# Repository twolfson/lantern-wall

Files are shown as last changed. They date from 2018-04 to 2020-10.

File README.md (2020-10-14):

# lantern-wall
Documentation for a glowing lantern wall

## Summary
While decorating my apartment, I decided to leverage a picture rail and attempted to make a wall of [Cloud Clouds][]

[Cloud Clouds]: https://learn.sparkfun.com/tutorials/led-cloud-connected-cloud

During the process, I realized that clouds would look too bulky for what I wanted as well as require a lot more thought to power/illumination

Now the result is one-off perf-boards with a CR2032 battery, LED, switch, and weak resistor

**Off:**

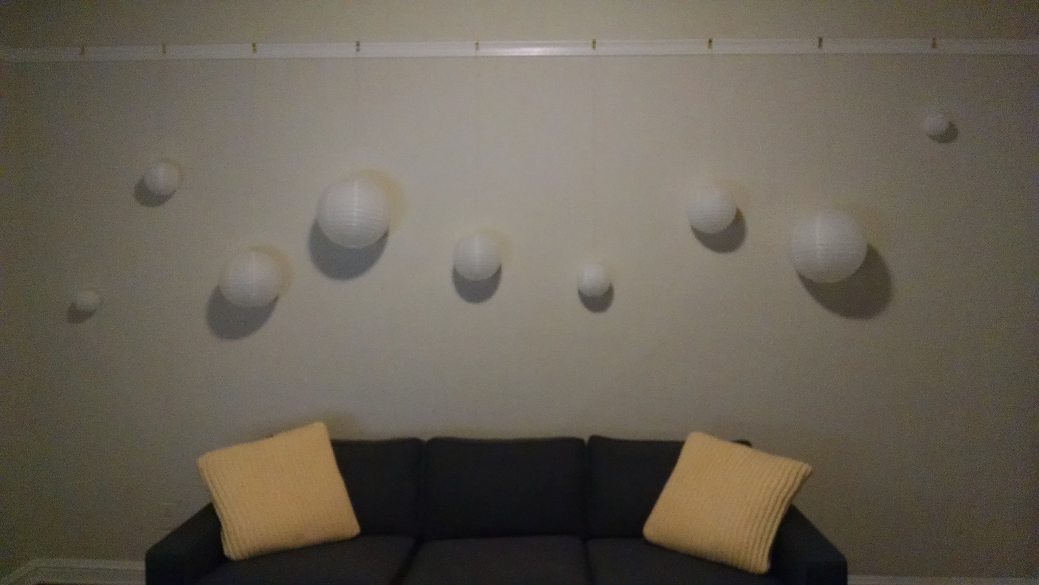
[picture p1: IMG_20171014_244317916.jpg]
Lanterns off


**On, room lights on:**

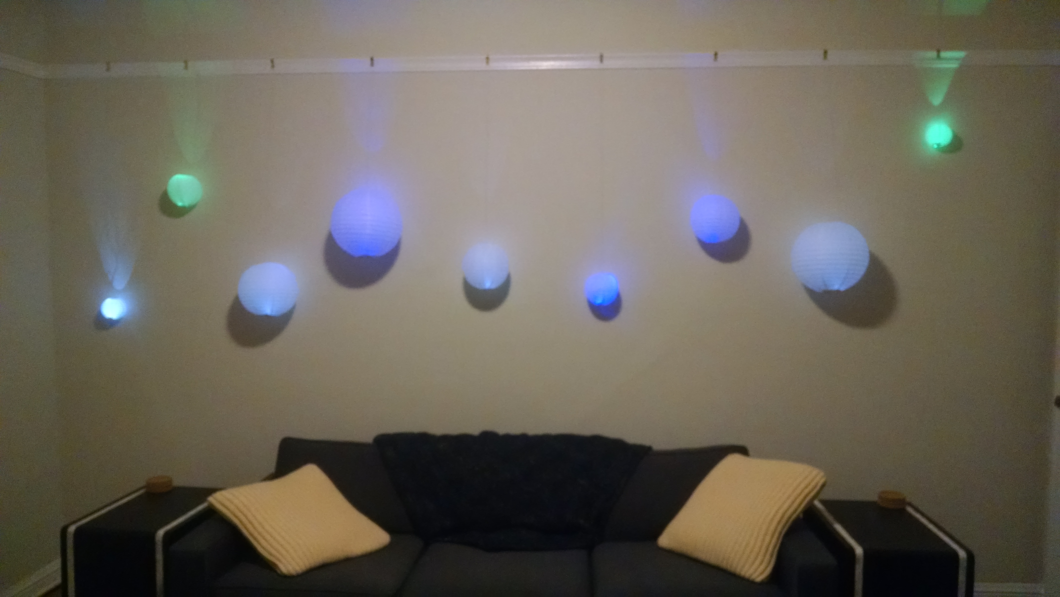
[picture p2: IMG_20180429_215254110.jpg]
Lanterns on, room lights on


**On, room lights off:**

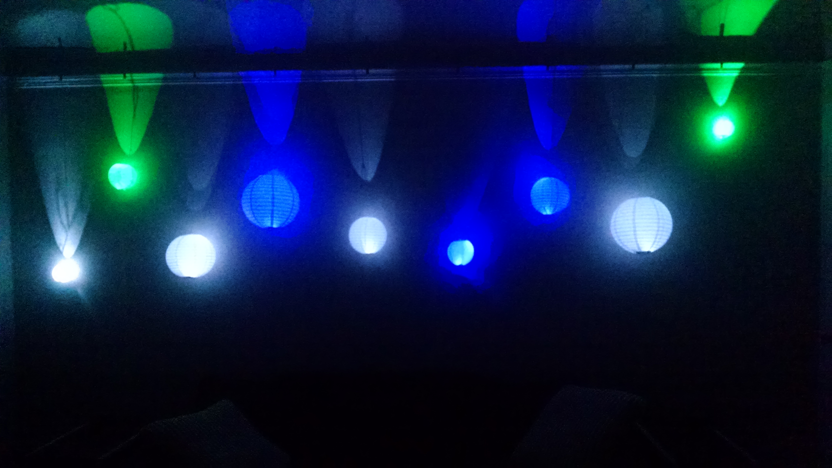
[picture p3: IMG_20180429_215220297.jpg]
Lanterns on, room lights off


**All photos:**

<https://drive.google.com/drive/folders/1h23Px1IOjGWnXOu8yB6WGrw3N42IKGuf?usp=sharing>

## Hardware
Each lantern has 1 or 2 boards in it. The boards are made out of perfboard so I have some rigidity and get some solder practice (I'm new to electronics)

**Circuit photo:**

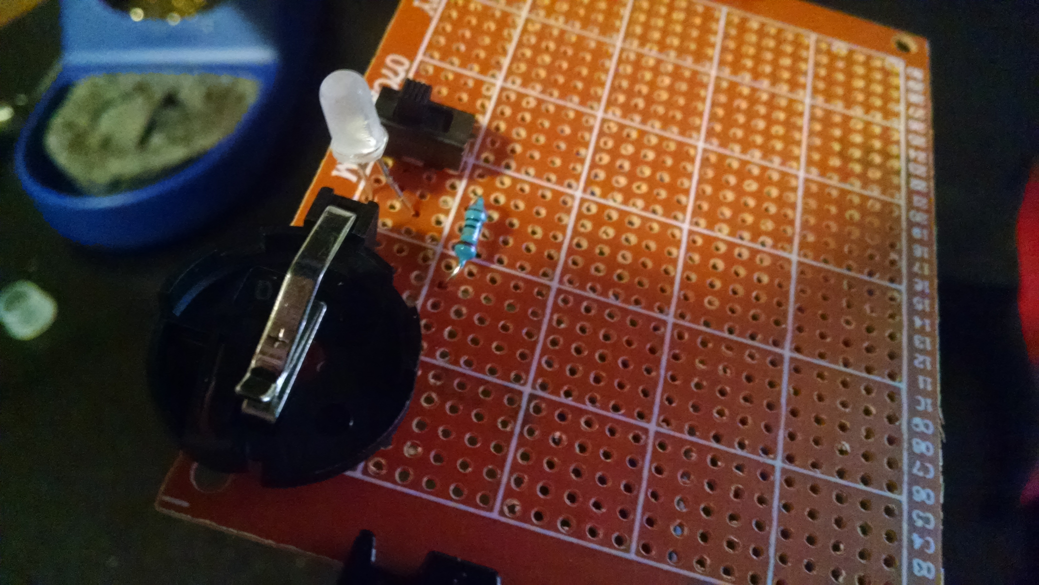
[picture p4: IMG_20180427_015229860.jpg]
Circuit photo


**Board components:**

- Perfboard, https://www.adafruit.com/product/2670
    - 1 perfboard used to create six boards
    - Effective price: $0.08/LED board
- CR2032 holder, https://www.amazon.com/gp/product/B00NQB2UNU/
    - Effective price: $0.60/LED board
- CR2032 batteries, https://www.amazon.com/gp/product/B071D4DKTZ/
    - Effective price: $0.70/LED board
- LEDs, https://www.amazon.com/gp/product/B01AUI4VSI/
    - We modified these with 400 grit sandpaper to diffuse them
    - Effective price: $0.08/LED board
- 10 ohm resistors, https://www.amazon.com/gp/product/B072BL2VX1/
    - Effective price: $0.02/LED board
- Switch, https://www.amazon.com/gp/product/B007QAJST6/
    - Effective price: $0.13/LED board

**Non-board components:**

- Lanterns, https://www.amazon.com/gp/product/B01M63OEBF/
- Picture rail hooks, bought at local hardware store
- String, bought at local sewing store

**Total prices:**

- Total price per LED board: $1.61
- LED boards made, excluding early lessons: 12
- Total price for entire project: $32.32

## Pros
- Boards are tiny and fit smallest lanterns
    - Had trouble finding something off the shelf, hence the boards

## Cons
- CR2032's aren't reusable
- Current for LEDs gets lower over time
    - Due to being new to electronics, I didn't realize batteries aren't constantly at their nominal output voltage
    - As a result CR2032 starts at 3.3V but then gets down to 2.7V
    - The result is the LED draws ~20mA then down to ~3mA leading in 10x dimmer brightness

## If I were to do it again
- Use lithium polymer batteries
    - Would maximize current and allow recharging

## Documentation
### Photos
We've uploaded all the photos from this project to Google Drive. The dates will correlate with the notes here

<https://drive.google.com/drive/folders/1h23Px1IOjGWnXOu8yB6WGrw3N42IKGuf?usp=sharing>

### October 14 2017
Hung up initial lanterns on picture rail utilizing string + tape to find ideal height

We also tried out using cotton on a cloud but didn't like the result so we left it as is for now

**Notes:**

- [2017-10-14-initial-hanging-readme.md](2017-10-14-initial-hanging-readme.md)
- [2017-10-14-dye-considerations.png](2017-10-14-dye-considerations.png)

### December 03 2017
Walking through Chinatown I saw this lantern display and took a photo

I don't think I ever registered it as the inspiration for this project but it probably was subconciously

### March 30 2018
Performed lighting tests for a single LED in a lantern, utilizing a breadboard

Figuring out logistics for putting a battery and board inside of the smallest lantern

**Notes:**

- [2018-03-and-04-planning.txt](2018-03-and-04-planning.txt)

### April 04 2018
All necessary parts arrived, soldered up our first board

My soldering inexperience is showing here with lots of doubly-thick solder runs

However it worked and I was thrilled

**Notes:**

- [2018-04-04-first-light.txt](2018-04-04-first-light.txt)

## April 10 and 11 2018
Taking time to explore new solder and research getting a respirator

It definitely made me more confident in future soldering and have a better understanding of what is going on

**Notes:**

- [2018-04-10-soldering-notes.txt](2018-04-10-soldering-notes.txt)
- [2018-04-11-deciding-on-respirator.txt](2018-04-11-deciding-on-respirator.txt)

## April 15 2018
Lots of things happening that day:

- Tried out new respirator with quick latch
    - Quick latch is soooo useful
- Soldered another board
- Noticed lighting in lantern was weird
- Contemplated different hanging/insertion approaches to fix directionality
- Proof of concept showed that it didn't matter where light was, it was a lack of diffusion causing issue
- Diffused the LED via 400 grit sandpaper, worked great in proof of concept
- Made a board with diffused LED, worked great
- Explored color ideas on computer
- Started to build proof of concept color circuits but it got too late

**Notes:**

- [2018-04-15-respirator-fitting.txt](2018-04-15-respirator-fitting.txt)
- [2018-04-15-making-boards.txt](2018-04-15-making-boards.txt)
- [2018-04-15-lighting-explore.png](2018-04-15-lighting-explore.png)
- [2018-04-15-lighting-explore-cool-colors.png](2018-04-15-lighting-explore-cool-colors.png)
- [2018-04-15-lighting-explore-cool-colors-without-uv.png](2018-04-15-lighting-explore-cool-colors-without-uv.png)
    - Went with non-UV variant to avoid freaking people out due to length UV exposure (despite likely being harmless UVA)

## April 22 2018
- Tried out a new solder to avoid splatter, still getting some splatter
    - Advice/feedback here would be much appreciated. Iron is at 750F, solder is lead-free rosin core 2%
- Tried out finding minimal resistance for LED via potentiometer :sparkles:
- Tried out color proof of concept with throwie-esque LEDs

**Notes:**

- [2018-04-22-color-proof-of-concept.txt](2018-04-22-color-proof-of-concept.txt)
- [2018-04-22-new-solder.txt](2018-04-22-new-solder.txt)
- [2018-04-22-resistance-testing.txt](2018-04-22-resistance-testing.txt)

## April 23 2018
Realized that CR2032 would need to be replaced at some point and isn't recharagable. Started a battery test to see how voltage, current, and battery life hold up over time. It's been still going as of 2018-04-29 ._.

**Notes:**

- [2018-04-23-battery-test.txt](2018-04-23-battery-test.txt)

## April 24, 26, 28, and 29 2018
Soldered remaining boards and hung them up to get our final product. Also did some calculations to see how much longer the battery test would go on for

- [2018-04-24-more-soldering.txt](2018-04-24-more-soldering.txt)
- [2018-04-26-even-more-soldering.txt](2018-04-26-even-more-soldering.txt)
- [2018-04-28-battery-test-visualization.xls](2018-04-28-battery-test-visualization.xls)
- [2018-04-29-final-hanging.txt](2018-04-29-final-hanging.txt)

Final product:

**Off:**

Lanterns off

**On, room lights on:**

Lanterns on, room lights on

**On, room lights off:**

Lanterns on, room lights off

## October 2018
We revisited the project to make it easier to turn lights on/off. The old process was:

- Wiggle circuit out of lantern
- Toggle switch
- Wiggle circuit back into lantern

Wiggling can take an annoying amount of time

We did some research and settled on the following triggering our lanterns:

- Magnetic reed switches, https://www.amazon.com/gp/product/B07239WZGF/
    - Effective price: $0.45/board
    - Buying excess of these is necessary as they are fragile and easily break when affixing to existing circuits
- Bar magnets, https://www.amazon.com/gp/product/B00BZ9YU88/
    - Effective price: $1.06/lantern

We can now slide in/out the bar magnet on the bottom of the lantern which is marginally easier and still consumes no power

## May 2020
After enough time, we found inserting/removing magnets each time was tedious to do for all 9 boards

We considered many alternatives (e.g. pull cord switch, capacitive touch, solid-state relays) and for a long time thought that low-current draw would be too high

We were wrong about low-current draw being too much, as 0.1uA from an [ATtiny85][] works great for our purposes =)

We settled on the [ATtiny85][] as opposed to other ICs for the following reasons:

- Through-hole solid-state relays draw more current in quiescent state (at least 1uA, vs 0.1uA for ATtiny @ 3.3V)
    - Example: https://www.digikey.com/product-detail/en/toshiba-semiconductor-and-storage/TLP222AF/TLP222AF-ND/871243
- Battery is only 200mAh so 2 years of idling drains 1% (~2mAh; `0.1uA * 1mA/1000uA * 2y * 365d/1y * 24h/365d`) vs 10% for `1uA`
- Easy wiring with built-in pull-up resistor for interrupt
- Discovered `PIC12F629` too late, which allows for `1nA` current on sleep, but already had ATtiny/AVR programmer
    - https://www.jameco.com/Jameco/Products/ProdDS/223790.pdf

We were also excited about features like:

- Keeping LED on while ATtiny is asleep (only works for `digitalWrite`/`HIGH`, no `analogWrite`/PWM support)
- Potential to use for twinkling (contrary to previous line)
- Potential to use for RGB LEDs, once we more thoroughly learn about power requirements and battery options

[ATtiny85]: https://www.microchip.com/wwwproducts/en/ATtiny85

We prototyped and created new boards with this setup, detailed info can be found in `2020-05-magnet-toggle.txt`

Additionally an [PlatformIO][] setup and perfboard [Fritzing][] layouts can be found in the corresponding `magnet-toggle` folder

The `.cpp` file in this folder is also compatible as an [Arduino][] sketch

> Using Fritzing after our first couple boards significantly sped up production since we didn't have to overthink placement as much

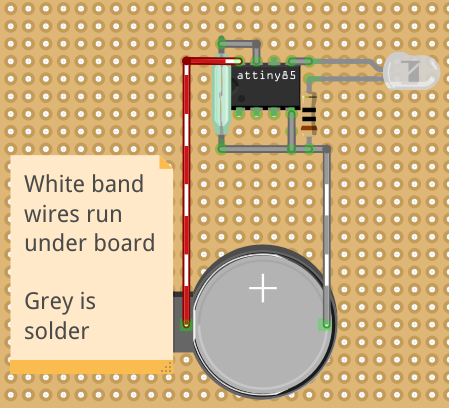
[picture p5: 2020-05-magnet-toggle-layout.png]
Fritzing layout


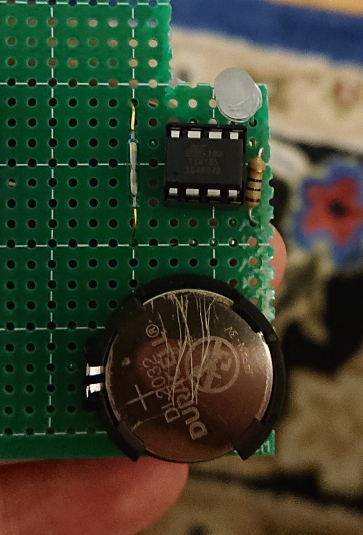
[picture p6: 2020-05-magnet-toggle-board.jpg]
Board result


[PlatformIO]: https://platformio.org/
[Arduino]: https://www.arduino.cc/
[Fritzing]: https://fritzing.org/home/

Bill of Materials (BOM) per 1 LED board:

- 7x9cm single sided perfboard, $0.75 each, https://www.mdfly.com/products/5pcs-hq-7-9cm-single-side-prototype-board-perforated-2-54mm-plated-breadboard.html
    - Can use a much smaller size in practice and pad out edges with cardboard underneath
- 8 pin DIP socket, $0.12 each, https://www.jameco.com/webapp/wcs/stores/servlet/ProductDisplay?productId=51571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
    - Kind of sticky to microcontrollers, recommend buying [DIP IC extractor](https://www.jameco.com/webapp/wcs/stores/servlet/ProductDisplay?productId=16838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) as well
- ATtiny85, $1.75 each, https://www.jameco.com/webapp/wcs/stores/servlet/ProductDisplay?productId=2151312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
- CR2032 holder, $0.55 each, https://www.jameco.com/webapp/wcs/stores/servlet/ProductDisplay?productId=355434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
    - These were much less brittle than the earlier versions we bought, very satisfied
- Reed switch - normally open, $0.50 each, https://www.mdfly.com/products/hq-2-7x14mm-reed-switch-no-pack-of-2.html
    - Highly recommend plastic over glass as glass can break easily during handling
- LEDs, $0.40 at most each
    - White, failed to get right brightness+color temperature from Jameco, went back to Chanzon, https://smile.amazon.com/gp/product/B01AUI4VSI/
    - Green, leftover from first iteration, https://smile.amazon.com/gp/product/B01AUI4VSI/
    - Blue, https://www.jameco.com/webapp/wcs/stores/servlet/ProductDisplay?productId=2274839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
- 10 ohm resistor, $0.06 each, https://www.jameco.com/webapp/wcs/stores/servlet/ProductDisplay?productId=690380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
- Not listed: Solid core wire, solder, CR2032 battery, etc

## Unlicense
As of Apr 29 2018, Todd Wolfson has released this repository and its contents to the public domain.

It has been released under the [UNLICENSE][].

[UNLICENSE]: UNLICENSE

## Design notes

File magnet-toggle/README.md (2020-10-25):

# lantern-wall/magnet-toggle
Magnet toggle source code for a lantern wall lantern

## Getting started
**Requirements:**

- ATtiny85 programmer, e.g. [Tiny AVR Programmer][]
- ATtiny85

[Tiny AVR Programmer]: https://www.sparkfun.com/products/11801

**Steps:**

Connect the ATtiny85 and ATtiny85 programmer to your computer, then run the following in a terminal:

```bash
# If PlatformIO isn't yet installed, we recommend installing it via `virtualenvwrapper`
# mkvirtualenv lantern-wall

# Configure out ATtiny85 fuses
platformio run --target fuses
# Processing attiny85 (platform: atmelavr; board: attiny85; framework: arduino)
# ...
# avrdude done.  Thank you.

# Program our board
platformio run --target upload
# Processing attiny85 (platform: atmelavr; board: attiny85; framework: arduino)
# ...
# avrdude done.  Thank you.
```

The ATtiny85 is now programmed and ready to be used in a circuit.

Please see the [Fritzing][] files (`.fzz`) for wiring layout

[Fritzing]: https://fritzing.org/home/

## Documentation
### Development
If rewriting the script, then we recommend doing all dev on the programmer itself:

- Connect jumper wires to interrupt pin (PB2) and GND, then connect them to simulate a switch closing

If doing more detailed exercises like determining power usage, then V_CC will need to be proxied somehow which cannot be done in place

As a reminder: A 3.3V powered ATtiny cannot be powered by a 5V USB jumper, not only due to being on a different V_CC and GND but also due to different logic levels

Additionally, using 5V power with an LED might cause burnout, if the resistor is too weak

In short, it's probably best to build a development board which has a resistor sturdy enough for 5V and headers for jumping everything from the programmer board (including a V_CC proxy)

## Architecture
We use PlatformIO for our project, to avoid dancing between different Arduino IDE setups

As well as document our setup itself as code (e.g. clock speed, fuses)

## Notes
- Starting point for current code: 0.2uA LED off, 1.67mA LED on
- We tried downclocking it but have bricked the ability to program it .\_. https://www.avrfreaks.net/forum/attiny85-configured-128-khz-internal-oscillator-does-not-program-anymore
  - The ATtiny85 still does work for our lanterns, but yea. Stuck at unable to program =/
  - Going to put it off to the side
- Moved to newer code and fuses, seems to use same 0.1uA when LED off but 1.90mA with LED on
- Rolled back code and fuses, power consumption is indistinguishable (only real changes were analog comparator disable and pins change)
  - Though couldn't turn on LED in 200uA multimeter mode with new code/fuses. Possibly requires CKDIV8 for slower/less power hungry boot
- We've confirmed that it was the CKDIV8 fuse, rolling back that change now
- Probably won't reprogram all the boards since not a necessary change but good exploration for ourselves =)

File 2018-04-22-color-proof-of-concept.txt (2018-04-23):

Exploring color proof of concept

Initial attempt:

- Take a CR2032
- Put it in a holder
- Wrap resistor around 1 pole and tape it
- Wrap LED around other pole and tape it
- Connect remaining ends and tape them together

Doesn't work very well. Components too loose

Second attempt:

Make a throwie minus the magnet

- Take a CR2032
- Put LED on both its ends
- Tape it
- Done

Good, just don't hold it for too long due to no resistor

Could also inline a resistor for the LED but don't really want to

-----------------------

Okay, back and deciding to still use a resistor. It was bugging out with the LED a little earlier

Going to also diffuse all LEDs for this experiment

- [5 of 5] White LEDs (3 singles, 1 double)
- [4 of 4] Blue  LEDs (2 singles, 1 double)
- [2 of 2] Green LEDs (2 singles)

After some more trial/error, layout attempt that works best is to make both LED and resistor linear/tightly packed battery then wrap their ends

This minimizes the leads slipping from the tape

```
// Off/disconnected
      & // LED
     * *
 ****   ***
+++++
-----
 ****   ****
     ~~~  // Resistor

// On/connected
      & // LED
     * *
 ****   *
+++++    ** // Twisted wires
-----    ***
 ****   *
     ~~~  // Resistor
```

It also helps to do an L bend on the battery side so they resist flipping

Ammeter checks:

- Green LED: 10mA with 10 ohm resistor
- White LED: 8mA with 10 ohm resistor
- Blue LED: 8mA with 10 ohm resistor

I'm going to bet they'll be a little more in a breadboard, no idea in circuit since we'd need to break the circuit (e.g. pluggable wires)

Since we had 20mA on breadboard previously

All done and wired up

The board LED is definitely brighter than the taped LED

Connected all of the LEDs

It turns out I miscounted and needed to use a non-diffused LED

Everything looks good

The brightnesses do vary a lot but I think that's alright

It's art, it doesn't have to be perfect/consistent

The proper fix for this would be to swap our the resistors with potentiometers and tune the resistance appropriately

Correction to my previous claim about being unable to test circuit board with an ammeter. It's possible if we turn off the switch and short-circuit around it with the ammeter

Anyway, going to move forward with 10 ohm boards for each LED

And add 1 more white LED to the list

The pattern goes from left to right

- Size 1. 1 white LED
- Size 2. 1 green LED
- Size 4. 2 white LEDs
- Size 5. 2 blue  LEDs
- Size 3. 1 white LED
- Size 2. 1 blue  LED
- Size 3. 1 blue  LED
- Size 5. 2 white LEDs
- Size 1. 1 green LED

Totals:

- White LEDs: 2 singles, 2 doubles (4) (6 total)
- Green LEDs: 2 singles, 0 doubles (0) (2 total)
- Blue  LEDs: 2 singles, 1 double  (2) (4 total)

Plan once we've created all our boards:

- For larger lanterns, take some cardboard and place boards on that. Tape them down for easy in/out

For proof of concept, we used blue painter's tape (we were out of electrical) to seal up holes to toss in proof of concepts

Fun fact: The proof of concepts were bright enough to illuminate the room with main lights off =3

Getting late, calling it for the night

Tested out the ammeter with the circuit. The theory works though somehow it's only 5mA. Maybe the battery died enough over time. Yea, it's already down to 2.8V

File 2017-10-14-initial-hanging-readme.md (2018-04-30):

# Lanterns
Wall art for our apartment

This was initially inspired by SparkFun's Cloud Cloud video but after purchasing the lanterns, LEDS, and cotton. We felt insecure about the LEDs for heat and powering issues

We've decided to defer on cotton to make them clouds for now. So here are the results as of 2017/10/14

We've also tossed around the idea of dying the clouds (e.g. dark purple, green, orange, blue). Likely psychadelic but with sunset tones

## Action log
Bought lanterns for LED filling + cloudifying
Decided to start with basics via hanging + no clouds

Sketched out placement options

Put up with long lengths of string

Used tape to adjust lengths without cutting

Measure lengths with tape adjustments

Take down each 1 by 1 and cut string to measured length

## Notes
Taped heights:
Length of string from hook to fixture. Excludes width of wire and fixture
  Wire - Unnoticable. Fixture - 0.625
Lanterns from left to right. 9 total.

  5 sizes. 2x of each but removed 1 due to hitting door
39.625. Smallest -> never modified. Guess 40.25

18.25. 2nd smallest -> never modified. Guess 18.875
32.75. 2nd largest -> never modified. Guess 33.325
19.5. Largest -> 21.125
29.125. 3rd (medium) -> 29.75
34.25. 2nd smallest -> 34.625 after cuts
21.25. 3rd (medium) -> 22 after cuts
26. Maybe -.25 due to middle wire attachment. 1st largest -> 26 after cuts
10. Smallest -> 10 after cuts

## Photos
IMG_20171013_242444325.jpg - Initial placements, some height adjustments via tape
IMG_20171013_010216388.jpg - Rearrangements + final tape adjustments
IMG_20171014_244317916.jpg - Resized string based on tape adjustment measurements
Everything else - Dated sketches for arrangement

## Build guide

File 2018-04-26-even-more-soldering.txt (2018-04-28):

Going to solder using wires this time. Haven't yet bought a window screen (meant to today) so going to avoid opening a window until later. Hopefully reduced solder usage is good enough

- Blue LED
- Was able to lay out with only using IC leads
- Looks good, a little hard to force down resistor leads with iron but good
    - Prob easier to do with hand then solder
    - Still getting splatter from solder =/
- Much faster too
- Trying out
- Good
- Cut, sand, resolder battery as it feels loose, sand more, good, neeeext!

- Anothe blue LED
- 12:16AM
- Prepping ICs
- Discovered the CR2032 has a little missing plastic so it can easily drop its gate. So clever yet secret
- Broke first battery holder terminal ._.
- Done placing at 12:26AM
- Started soldering, had a bit of a hiccup with leads conflicting with each other and over soldering, good now
- Done soldering at 12:33AM
- Lol, nvm -- missed positive terminal
- Fixed, now done at 12:36AM
- Have to wait for it to cool so going to start on another one in parallel

Testing/clipping CR2032 holders and switches
6 clipped, 6+6 tested, and good!

- Board is cooled, battery in, looks good
- Cut, skipping sanding for now (can do in bulk too)

- 12:44AM
- White LED
- Placed, clipped eagerly, soldered, looks great!
- 12:53AM
- Cool enough, drop gate, load battery, works!
- Cut it up
- 12:56AM
- Wow, so fast -- 12 minutes as opposed to 20 or 30

- Blue LED
- 12:57AM
- Wow, new record or something
- 1:04AM, done
- Waiting for it to cool
- Soldered in a new CR2032 battery holder for next one
- Blue is good
- Cutting now
- Done, good. 1:09AM

- Green LED
- 1:09AM
- Soldered, same as last one
- Battery in and good
- 1:16AM
- Cut again, no sand

- 1 thin board with space for 2 circuits
- Soldered both CR2032 holders on eagerly due to leveling/vice issues earlier
- 1:25AM
- Double setup up and soldered both circuits
- Was nice for simultanoues cooling of leads
- 1:39AM finish
- Cut again, no sand

- 1:43AM
- Last one board, white LED
- Solder in CR2032 holder, so much easier than pliers
- Fuck, a lead clipping went under a keyboard key =(
    - Prob need to pop-out keyboard to fix it
- Finished soldering
- Battery in, good!
- 1:52AM
- Cut out

- Sand all our 7 boards
- 2:14AM
- Done
- Done with everything

- All boards light up
- Going to try placement another day since it's now quite late
- Really happy with progress though

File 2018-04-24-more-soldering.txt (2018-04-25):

After getting through the initial portion of the battery testing, we've decided to continue building out the boards

Not much new things to note so going to bullet it out:

- Built blue board looking at diffused white
- Battery is accessible
- LED polarity is correct
- Soldered it up
- Verified connectivity
- Waiting for it to cool
- Added battery, missed a spot. Fixing
- Reverified connnectivity
    - It's neat how we can do connectivity for all one-way binding due to LED's diode nature (it's in the name, yey)
- Cooled, battery, good
- Mark, cut, sand, disco

- Same for a white LED
- Keep in burning flux due to staying/revisiting pad too often before letting it cool
- Connectivity good
- Cooling taking too long, cut now
- Sand
- Battery, good
- Disco

Taking approximately 20-30 minutes per circuit

- Green LED to round it out
- Same layout again
- 1:29AM
- Almost improperly rotated battery holder. Phew
- If the pad is smoking after you're done, it's likely due to overheated flux
- Soldering complete, lots of burned flux =(
- 1:47AM
- Maybe should start using wires instead of solder runs...
- Connectivity good
- Cut, sand
- Battery
- Looks good
- 1:55AM

New solder still leaving lots of little splatter everywhere

It might be me or the iron or the temperature...

Also need to open window, noticable smell despite using fume exhaustor and respirator

Calling it for the night

**Next time:**

- Open a window
- Use less solder by using wires

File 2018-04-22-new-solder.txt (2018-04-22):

I replaced the solder to see if we could reduce the splatter. Here are my notes

Feels similar

Still does the reflective when hot, matte when cool which is great

Beaded them just fine

Going to try joining runs now

It wsa non-trivial once again but got it done

I'm not seeing the specs of solder stick to the iron tip when I'm done cleaning which is a good sign

I think that was probably the best indicator

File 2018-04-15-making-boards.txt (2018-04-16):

We've got our new resistors in and now know that a CR2032 is 3.3V nomially so we should figure out how to maximize our amperage and see how it affects brightness

White LED:
  Forward voltage: 3V-3.2V
  Max amperage: 20mA

I think we can choose anywhere in range so let's go with high end

Total voltage = LED voltage + resistor voltage
White LED:
  3.3V = 3.2V + V_r
  V_r = 0.1V

V=IR
White LED reisistor:
  0.1V = 0.02A*R
  R = 5ohms
  Closest we can get is 10ohms
  This makes current:
  0.1V/10ohm = I
  I = 0.01A (10mA)

  Previously for 220ohm:
  I = 0.0005A (0.5mA)
  Reading this from a multimeter: 2.58mA so calculation might be off somehow...
  V = 2.58mA*220ohm = 0.57V
  Weird, the multimeter voltage is correct too:
  2.6V to LED, 0.6V to resistor

  Going to play it safe and multiply the actual amperage to 20mA:
  20mA/2.6mA = ~7.7x
  220ohm/~7.7x = 28.6ohm
  Next closest: 47ohm

  47ohm result. Definitely brighter
  Oddly voltage changed:
  2.86V to LED, 0.42V to resistor
  8.4mA (measured)

  Let's go up to 20ohm...
  Even brighter!
  2.98V to LED, 0.3V to resistor
  15.0mA (measured)

  Adafruit says we can go up to 30mA? o_o
    https://learn.adafruit.com/all-about-leds/forward-voltage-and-kvl
  Prob going to say 20ohms is fine. Might try it out though for education >_> <_<

  10ohm resistor
  20.6mA (measured)
  3.07V to LED, 0.21V to resistor

Why are resistors at 10, 22, 47 variants?
  It's logarithms. Thanks logarithms
  https://electronics.stackexchange.com/a/68023

It looks like it's normal for LEDs to vary voltage draw based on current
  Also varies with temperature
  https://electronics.stackexchange.com/a/173477

Also, I've been reminded to verify the resistor can handle the power dispersion
White LED resistor:
  P = VI
  P = 0.21V * 20.6mA
  P = 0.0043W (4.4mW)
  also
  P = V^2/R
  P = 0.21V^2 / ~10ohm
  P = 0.0043W (4.4mW)

Went back to measurements and verified resistor is true, damn variable LEDs =/

Resistor ohms (V=IR; R=V/I): 20.0ohms
Resistor ohms (V=IR; R=V/I): 10.2ohms

Second board completed

First laid out components, once again optimizing for vertical narrow layout

Then soldered them in place

I was much more confident this time

Unfortunately, the LED and resistor weren't secured properly so they were off the board when I was done

I loosened solder with heat and repositioned, broke pads, but eventually got them

Clipped leads

Then I beaded out would-be leads including double-checking LED polarity

Then I soldered everything together

Unfortunately, I accidentally soldered the switches leads

There has to be a system to know when to not solder tight component leads to itself =/

Maybe sharpie or coloring it

Also had to lay board level due to solder being affected by gravity

Got it much cleaner this time than v1

Now waiting for board to cool before using CR2032 socket. We don't want to over-harden its metal again

Verified its continuous though

Plugged it in, looks great!

Sharpied where to cut to prevent overcutting top/bottom

Cut out with scissors

Sanded edges/corners with P50, P100, and P180 sandpaper

Looks great. Trying it out now

It fits and works! It's even smaller than the last one

It's so bright the LED is visible within the smallest lantern ._.

There is a weird light pattern going on, I really want even LED lighting

Maybe we can run wires instead and make it suspended in the center of the bulb somehow?

A few ideas:

- A hard support structure for the LED (e.g. tape/shrinkwrap)
   - Would be difficult to insert into lanterns, maybe there's a smaller alternative
   - Could do a wire but it's not guaranteed
- Wire/clip in board at top of lantern and suspend LED down
   - Possible but clipping in is prob easier said than done
- Same board but LED is on a fixed-length wire
   - Would make colors specific to lanterns
   - Could make them headers
   - Still have voltage restriction
   - We might have this problem no matter what due to brightness of larger lanterns

Yea, let's proof of concept that last one...
   It would be much easier with a quarter bread board

Also need to verify brightness works for large/small (i.e. 1 LED still good in large, maybe 2 LEDs + batteries

Verified that 1 LED and current size board prob won't be enough for large lantern

Let's build out the sizes 1-3 lanterns though

Strategy 1:
- Use (string + cut) or (tape measure) to find ideal length of wire
- Affix LED to wire, prob via electric tape (don't have any F to F headers
- Breadboard it and get overhang version working
- Solder LED to proper length wire
- Wire up a board, solder it, use it

Maybe wait for a second...
Use breadboard again to find ideal placement

It looked like at being just at the bottom of the lantern was fine...

Also, definitely need to upsize board for size 3 but LED is fine

Took a break for food

Thought of a couple new strategies:

- Simply tape the LED and coin cell together, then tape on string and hang it. No board needed
- If we go with a circuit board, we should mount the wire on the other side of the board so it's easier to access the switch from the bottom instead of through
- Improvement on top of that: create a board with a wire soldered into it (or string) for it to hang from
    - Add traces for LED. Add LED hanging off of board

```
  ( + )   // Wire connecting to lantern hook
 (  !  )  // Wire
(   |   ) // Circuit board
 (  *  )  // LED off of circuit board
  (   )
```

Strategy for that new one:
- Evaluate height of current board variant, verify it's short enough for smallest lantern
- Run string through perfboard, verify it can be hung

Another strategy:

- Free-hand circuit with everything wired with no board (heavily inspired by SparkFun's video about it)

Tried out putting a wire in an existing board to hang it. It works :+1:

Now trying standalone breadboard again

LED lighting feels off, have to be an extreme end of lantern to get diffusion. Want to explore diffuser caps

Going to try out a 400 grit sandpaper hack... read about one in an earlier post and Instructables agrees
  http://www.instructables.com/id/how-to-defuse-an-LED/

Wow, that solved it so well. No more cut off problem. It's gone =D

Now to build another board with this diffused LED

Set up board with elevated LED this time too

Also clipped 1 of the switch's edge leads as we don't need both and it complicates things

Trick for short terminal CR2032 holder, used pliers to turn out pins

Soldered everything nicely then realized that logistically battery holder was backwards =(

Solder suckered it out successfully

Beaded again, soldered lines again

Definitely gave self harder situations

Getting much better though, keeping things flat helps a lot

Done, continuity looks good. Switch works when we want it to

Have a bit of popped solder, going to reheat it

Done, looks good

We keep on burning flux on tip of soldering iron. I think it's normal but annoying to clean, tip, solder, clean, etc

Waiting for circuit to cool before trying it out

Added battery, looks great

Sharpie, cutting, sanding edges, trying out in lantern

It works fucking amazingly. Fuck yessss

Okay, now we have to build lighting for all our lanterns

Going to call it for tonight

...

It keps on going for a bit more

I started exploring color schemes as I might need lead time to buying new LED colors

I took previous mocks for dye and altered it

I also created an array of LEDs on a breadboard to see current color options

Settled on decent white/blue/green mix for now

...

Did one more task for the night after trying to figure out proof of concept for colors

I set up alligator clip test for 2 white LEDs in series on largest lantern to see if we'd want/need more batteries/battery holders. I'm torn to be honest but it's better to be safe than sorry (time lags suck) so I'm getting 10 more of each

**Next steps:**

- [n] Buy a smaller breadboard for easier prototyping. Maybe even a tri-pad stripboard with headers
    - This might have been more of an impulse thought. Deferring for now
- [ ] Figure out lighting requirements for larger lanterns (using diffused LEDs)
- [ ] Figure out how to upsize boards for sizes 3-5 lanterns
- [x] Figure out desired color scheme
- [ ] Proof of concept colors with 10 breadboards and possibly F to F jumper-pinned wires
    - We could build out + solder boards but arguably this is cheaper
    - Maybe there's a middleground with header pins so we can swap out bulbs easily. Also acts as a nice standoff. Just not for smaller cases
    - Was about 55 tie point breadboards but realizing we can use alligator clips instead which I have a looot of :muscle: (thanks Makey Makey)
    - We only have 10 clips and it takes 3 but honestly, we can prob tape them
    - I'm getting too tired to keep on diving into this. Deferring for another night
- [x] Look into solder splatter
    - Caused by using flux boiling/too much flux 
        - https://stainedglassexpress.com/blog/2012/04/why-does-solder-bubble-and-splatter-when-soldering/
    - Also can be quality of solder. Try a different one
        - https://forum.allaboutcircuits.com/threads/reducing-solder-splatter.101820/
    - Apparently avoid "no-clean" due to cleaning annoyances
    - Going to go with Kester, seeing its name in Google search
        - https://electronics.stackexchange.com/questions/117781/what-lead-free-solder-type-is-convenient-to-use-on-hand-soldering
        - https://electronics.stackexchange.com/questions/186069/what-does-no-clean-solder-actually-mean
    - Going with Kester Solder 83-7068-1402 as its the only Kester lead-free in small sizes that Amazon has
        - It's got a "48" resin activated rosin core which should be good
        - http://www.nteinc.com/kester/download/83-7068-1402.pdf

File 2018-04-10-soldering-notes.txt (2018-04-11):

Tried out soldering with new lead-free solder as well as playing around with temperature

750F + lead-free solder

Melts well, can easily see when it's back to reformed (shiny -> matte)
Still burning board easily
Solder sticking to iron a lot

Moved to 450F

Solder not melting at all
Board not burning either though

Moved to 550F

Need to heat up the solder a little but getting a lot of control
Able to cool sculpt the solder with the iron

Moved to 500F

Not melting not like 450F

Moved to 600F

Solder melts quicker
Starts to brown board a little if I linger, nothing substantial though

Moved back to 550F for remainder

This seems good
Although cool sculpting isn't preferred; solder might not be mechanically sound if we don't let it fully melt according to Adafruit
Still was able to draw a square nicely =3

Definitely not going back to 750F any time soon

Going to play with solder sucker and jumpers now

-----------

Now reading through https://learn.adafruit.com/adafruit-guide-excellent-soldering/preparation

They say 750F for lead-free... ;_;

I guess I better try to get better...

-----------

Okay, results are in

It was sloppier but it's probably the right way to solder

Need to learn to not linger on joint

Need to learn to learn to wait for solder to cool before joining for a long run

The gloss/matte effect really really helps

It allows me to verify that the solder is melting properly

As well as how much of it is melting to know when I'm overmelting a part of a run

Oh, and I'm aware of cleaning the tip more often

Also started using a respirator mask but the internet seems to say it's doing nothing for chemical fumes...

-----------

Did 1 more run with a 3x3 square

Did it perfectly with 0 charring on other side of board

I think I'd ready =D

I should prob practice with wires and desoldering now too though

Oh well, it's 1AM. I'll do it another day

**Remaining tasks:**

[x] Figure out if this perfboard's contacts are difficult
  Nope, it was my skill level and solder
[ip] Try making lots and lots of tests via spare wire + solder
  Perfboard, wire, and solder are cheap
  http://www.instructables.com/id/Soldering-102%3a-Soldering-a-jumper/
[x] Figure out how to not burn board... I'm guessing it's be precise and fast. Don't linger
  Yep, don't linger ;) Also a good solder helps
[x] Round corners of cut out items via Dremel or sandpaper -- Did this last time, it worked great
[ ] Figure out better light diffusing strategy (could be raise LED via hot glue (still 1 sided), place 2 LEDs on opposite side of board (need more power))
[n] Play around with wire wrap and joining to jumper wires to "IC" connections
  I think we'll be fine

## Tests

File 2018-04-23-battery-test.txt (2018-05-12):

We're realizing that CR2032 aren't particularly rechargable so to avoid going through them like candy, we'd like to verify that the battery life is good in practice

Starting with a fresh CR2032. Voltage reading is 3.3V. Amperage is 7.5mA

Estimate based on 240mAh will be: 32 hours (240/7.5)

Prob going to pause/play a bunch to avoid missing end

Times:

- 2018-04-23 8:11PM to 1:39AM (5h 28m, total: 5h 28m)
    -  9:50PM, still going strong
    - 10:45PM: still going. 2.87V, 3.6mA -> 67 hours
        - Prob having some brightness loss but can't tell because it's subtle and over time
    - 12:49AM: still going. 2.87V, 3.45mA
    -  1:39AM: still going. 2.87V, 3.47mA
- 2018-04-24 6:34PM to 2:01AM (7h 27m, total: 12h 55m)
    -  6:34PM, 2.85V, 4.45mA (straaange)
    -  8:27PM, 2.80V, 3.30mA
    - 10:00PM, 2.79V, 3.08mA
    - 11:52PM, 2.80V, 3.23mA
    -  2:01AM, 2.76V, 2.84mA
- 2018-04-25 10:34PM to 1:51AM (3h 17m, total: 16h 12m)
    - 10:34PM, 2.82V, 3.93mA (a lot higher, usually 2.8-3.3mA)
    -  1:51AM, 2.78V, 2.94mA
- 2018-04-26 10:15AM to
    - 10:15AM, no recording due to other initial reads being high
    -  9:34PM, 2.76V, 2.42mA (11h 19m, total: 27h 31m)
    - 2018-04-27
    -  2:15AM, 2.69V, 2.20mA (16h  0m, total: 32h 12m)
    -  8:52AM, 2.73V, 2.14mA
    -  6:47PM, 2.72V, 1.82mA
    - Changed multimeter battery @ 7:20PM
    -  7:20PM, 2.74V, 1.93mA (33h  5m, total: 49h 17m)
    - 2018-04-28
    -  2:00AM, 2.71V, 1.71mA (39h 45m, total: 55h 57m)
    -  2:44PM, 2.70V, 1.37mA
    -  9:36PM, 2.69V, 1.23mA (59h 21m, total: 75h 33m)
    - 2018-04-29
    -  3:11AM, 2.67V, 1.01mA
    - 11:46AM, 2.67V, 0.86mA (20mA); 0.600mA (2mA)
    - 2018-04-30
    -  2:38AM, 2.63V, 0.50mA (20mA); 0.398mA (2mA)
    - 10:19AM, 2.62V, 0.42mA (20mA); 0.336mA (2mA)
    -  7:23PM, 2.60V, 0.34mA (20mA); 0.287mA (2mA)
    - 2018-05-01
    -  1:22AM, 2.60V, 0.22mA (20mA); 0.237mA (2mA)
    - 10:29AM, 2.60V, 0.22mA (20mA); 0.198mA (2mA); 99.3uA (200uA)
    - 2018-05-02
    -  1:03AM, 2.57V, 0.15mA (20mA); 0.134mA (2mA); 81.7uA (200uA)
    - 10:17AM, 2.57V, 0.13mA (20mA); 0.120mA (2mA); 75.2uA (200uA)
    - 2018-05-03
    -  1:03AM, 2.56V, 0.09mA (20mA0; 0.087mA (2mA); 61.0uA (200uA)
    - 10:07AM, 2.55V, 0.09mA (20mA); 0.082mA (2mA); 58.7uA (200uA)
    - 2018-05-04
    - 12:05AM, 2.54V, 44.5uA
    - 10:08AM, 2.54V, 41.1uA
    - 2018-05-05
    -  1:38AM, 2.53V, 34.3uA
    -  2:08PM, 2.52V, 29.5uA
    - 2018-05-06
    -  1:34AM, 2.51V, 23.4uA
    - 12:50PM, 2.51V, 21.7uA
    - 2018-05-07
    -  1:11AM, 2.50V, 18.2uA
    -  9:58AM, 2.50V, 16.3uA
    - 2018-05-08
    -  1:07AM, 2.49V, 14.0uA
    -  9:56AM, still on
    - 2018-05-09
    -  1:48AM, 2.48V, 10.7uA
    -  9:13AM, 2.48V, 09.3uA, side not visible but top is
    - 2018-05-10
    - 12:21AM, 2.47AM, 08.2uA
    - 10:00AM, still on
    - 2018-05-11
    -  1:27AM, 2.46V, 06.1uA
    -  9:00AM, still on
    - 2018-05-12
    - 1:56AM, 2.45V, 05.2uA
    - Stopped due to getting tired of recording when light is barely visible
    - Probably unusable after 1mA

SparkFun has been informative that batteries often start a few fractions of a volt about their nominal voltage (e.g. 4.3V for 3.7V nominal lithium polymer, 1.5V for 1.2V nominal AA/AAA)

https://learn.sparkfun.com/tutorials/battery-technologies/lithium-polymer

Learning that CR2032 has nominal discharge of 0.2mA

https://cdn-shop.adafruit.com/datasheets/maxell_cr2032_datasheet.pdf

Based on the lower right graph, it looks like we're running into a limitation caused by battery itself

Could pulse at 6.8mA but there's prob an issue with non-pulse

http://data.energizer.com/pdfs/cr2032.pdf

-----------

# 2018/04/24

It's not the battery's discharge limiting us. It's the LED limiting the current due to the battery's voltage

https://www.electronics-tutorials.ws/diode/diode12.gif

As the voltage to an LED increases, its current increases

Each LED color has different ideal voltages but 3.0-3.2V is normal for the ones we're using

Unfortunately CR2032 is dipping under 3.0V for our usage =/

We'd probably be better off with 3.7V batteries but I think CR2032 might be good enough for the project as is

We aren't looking to always maximize lighting and this avoid risks of fires

And definitely lasts for at least 12 hours (probably 60 based on existing guesses)

Going to go ahead and wire up remaining circuits. We can always hack them later and they're low cost

------------

# 2018/04/28
Impressed at how long the life span of this CR2032 is

Already up to 75 hours (cumulatively 3 straight days)

I'd love to see a graph of this so far, see how much juice it's used (hello riemann sums), and predict out how long it still has left

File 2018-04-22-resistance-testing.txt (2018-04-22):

Thought of this on April 17 but didn't have time to try out until now

To determine the ideal resistance for an LED:

- Take a potentiometer
- Set it to its maximum resistance (verify via multimeter)
- Wire up an LED circuit using potentiometer as its resistor
- Wire multimeter into circuit as an ammeter
- Drop potentiometer resistance until we hit 20mA current
- Break circuit
- Test resistance value of potentiometer
- This is our ideal resistance for maximum brightness

So how does it work in practice? Not too well, at least not too well with the potentiometer I have. I'd be a weaker one would be much better

I have a 50k ohm potentiometer so getting between 10 and 20 ohms is very very difficult (especially when a little drunk)

The 3.0-3.2V LEDs only got up to 10mA with the potentiometer at its 0 mark (apparently 1-2 ohms but was able to previously get 20mA with 10 ohms so not 100% on this)

It worked decent with 2.0-2.2V LEDs (mostly would like it easier to not go over the boundary)

I got ~21mA drawing and the potentiometer reads as 23.4 ohms

Still prob a good idea to try with a 47 ohm and 20 ohm resistor to see how they handle it

Apparently we can go over 20mA and the LED still works, prob ideal to not persist it though

Quick math:

Vcc = 3.3V
Vled = 2.2V

Thus, Vr = 1.1V

V=IR

1.1V=20mA*R
R=1.1/0.020
R=55ohm

Doesn't quite line up but I think I'm still learning =/

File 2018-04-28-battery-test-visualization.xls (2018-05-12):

Start time | Timestamp | Voltage | Current (mA) | Total time | Left-leaning Riemann (mAh) | Total mAh | We've excluded initial times as they're often higher than start
2018-04-23 20:11 | 2018-04-23 22:45 | 2.87 | 3.6 | 2:34:00 | 9.239999999 | 9.239999999 | We also excluded multimeter change time
2018-04-23 20:11 | 2018-04-24 00:49 | 2.87 | 3.45 | 4:38:00 | 7.13 | 16.37
2018-04-23 20:11 | 2018-04-24 01:39 | 2.87 | 3.47 | 5:28:00 | 2.891666666 | 19.26166667
2018-04-24 18:34 | 2018-04-24 20:27 | 2.8 | 3.3 | 7:21:00 | 6.215000001 | 25.47666667
2018-04-24 18:34 | 2018-04-24 22:00 | 2.79 | 3.08 | 8:54:00 | 4.773999999 | 30.25066667
2018-04-24 18:34 | 2018-04-24 23:52 | 2.8 | 3.23 | 10:46:00 | 6.029333334 | 36.28
2018-04-24 18:34 | 2018-04-25 02:01 | 2.76 | 2.84 | 12:55:00 | 6.106 | 42.386
2018-04-25 22:34 | 2018-04-26 01:51 | 2.78 | 2.94 | 16:12:00 | 9.653 | 52.039
2018-04-26 10:15 | 2018-04-26 21:34 | 2.76 | 2.42 | 27:31:00 | 27.38633333 | 79.42533333
2018-04-26 10:15 | 2018-04-27 02:15 | 2.69 | 2.2 | 32:12:00 | 10.30333333 | 89.72866667 | Approx discharge amount: 220mAh-240mAh
2018-04-26 10:15 | 2018-04-27 08:52 | 2.73 | 2.14 | 38:49:00 | 14.15966667 | 103.8883333
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

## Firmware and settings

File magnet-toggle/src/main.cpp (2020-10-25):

// Load in our dependencies
#include <Arduino.h>
#include <avr/sleep.h>
#include <avr/interrupt.h>

// Reference to framework constants
// https://github.com/vancegroup-mirrors/avr-libc/blob/06cc6ff5e6120b36f1b246871728addee58d3f87/avr-libc/include/avr/io.h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
// ATtiny25/45/85 vars: https://github.com/vancegroup-mirrors/avr-libc/blob/06cc6ff5e6120b36f1b246871728addee58d3f87/avr-libc/include/avr/iotnx5.h
// ATtiny85 specific vars: https://github.com/vancegroup-mirrors/avr-libc/blob/06cc6ff5e6120b36f1b246871728addee58d3f87/avr-libc/include/avr/iotn85.h

// Set up our constants
#define LED_PIN PB0 // Same as built-in programmer board for ease of use
#define INT0_PIN PB2 // Would use INT0 but that's "6" (bit in GIMSK (interrupt register)) when we need "2" for pin
  // https://github.com/vancegroup-mirrors/avr-libc/blob/06cc6ff5e6120b36f1b246871728addee58d3f87/avr-libc/include/avr/iotnx5.h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

// Set up our global variables
bool ledState = LOW;

// Define our functions
void setup() {
  // Set all pin modes, with default of INPUT_PULLUP to preserve power (p57, 10.2.6)
  static_assert(PB0 == LED_PIN, "Expected LED_PIN to be PB0");
  pinMode(PB0, OUTPUT);
  pinMode(PB1, INPUT_PULLUP);
  static_assert(PB2 == INT0_PIN, "Expected INT0_PIN to be PB2");
  // DEV: Interrupt pin is now set to trigger when shorted to GND, otherwise would need pull-down resistor with VCC
  //   See Fritzing schematic for clarification
  pinMode(PB2, INPUT_PULLUP);
  pinMode(PB3, INPUT_PULLUP);
  pinMode(PB4, INPUT_PULLUP);
  pinMode(PB5, INPUT_PULLUP);

  // Configure interrupts (p48+)
  GIMSK |= (1 << INT0); // Enable INT0 interrupt
  // In power-down mode, no edges, only level interrupt for INT0 (p34) so no MCUCR config
  // DEV: Technically in this mode, INT0 seems identical to PCINT*

  // Configure sleep
  set_sleep_mode(SLEEP_MODE_PWR_DOWN);

  // Minimize power consumption (p36, 7.4)
  //   Disable ADC (set ADEN to 0) (p136, 17.13.2)
  ADCSRA &= ~(1 << ADEN);
  //   Disable analog comparator (set ACD to 1) (p120, 16.2.2)
  ACSR |= (1 << ACD);
  //   Disabled BOD via fuses (see `platformio.ini`) (p41, 8.2.3)
  //   Disabled internal voltage reference, handled by disabling ADC, analog comparator, and BOD (p42, 8.3.1)
  //   Disabled watchdog timer via fuses (see `platformio.ini`) (p43, 8.4)
  //     Can be enabled programmatically even with this fuse set but we don't
  //   Explicitly configured port pins, handled at top of `setup` (p57, 10.2.6)

  // Set up our default LED state
  digitalWrite(LED_PIN, ledState);
}

void loop() {
  // Sleep immediately upon loop, all toggling occurs within `ISR`
  sleep_enable();
  sleep_cpu();

  // Token `delay` to give time to output any logging from `ISR`
  delay(100);
}

// When we receive an external interrupt on INT0
//   https://github.com/vancegroup-mirrors/avr-libc/blob/06cc6ff5e6120b36f1b246871728addee58d3f87/avr-libc/include/avr/interrupt.h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
//   https://github.com/vancegroup-mirrors/avr-libc/blob/06cc6ff5e6120b36f1b246871728addee58d3f87/avr-libc/include/avr/iotnx5.h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
//   These come from table on p48 of datasheet
ISR(INT0_vect) {
  // If our interrupt occurred on a rising edge (this runs on both rising and falling), then toggle our LED
  if (digitalRead(INT0_PIN) == HIGH) {
    ledState = !ledState;
    digitalWrite(LED_PIN, ledState);
  }
}

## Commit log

2018-04-02 Iterated further on lantern LEDs
2018-04-05 Added notes for first completed board
2018-04-11 Performed some soldering today with clear learning curve
2018-04-16 Started making more boards
2018-04-16 Tried out LED placements and shocked by improvements of a diffused LED
2018-04-22 Added resistance testing notes
2018-04-22 Added new solder notes
2018-04-23 Taped up all our LEDs for the proof of concept
2018-04-24 Starting battery test
2018-04-24 Continuing battery test
2018-04-25 Completed more battery test today
2018-04-25 Continued soldering
2018-04-26 Added more battery notes
2018-04-27 Going for long running battery test instead of short bursts now
2018-04-28 Continuing to test battery
2018-04-29 Completed visualization
    [2018-04-28 battery-test-visualization.ods]
2018-04-30 Added more battery timestamps
2018-04-30 Renamed files to consistent dash-case
    [2018-04-28-battery-test-visualization.ods]
2018-04-30 Exported .ora files to .png and moved from .ods to .xls for shareability
    [2018-04-28-battery-test-visualization.ods, 2018-04-28-battery-test-visualization.xls]
2018-05-12 Added edits from last time
    [2018-04-28-battery-test-visualization.xls]
2018-05-12 Completed battery test notes
2018-10-19 Added notes on magnetic switch
2018-10-19 Documented magnetic switch upgrades
2020-05-18 Added ATTiny85.ino functionality with external pull-down resistor
2020-05-18 Added Fritzing sketch for clarity
    [schematic.fzz]
2020-05-18 Clarified which pin was chosen and why
2020-05-18 Adding schematic for big lantern to sandbox with layouts
    [big-lantern.fzz]
2020-05-18 Made slightly improved variant of physical big board (no jumping reed)
    [big-lantern.fzz]
2020-05-18 Improved layout by flipping LED polarities so terminating next to resistor
    [big-lantern.fzz]
2020-05-18 Added visual clarity with black/red wires clearly starting on target sides
    [big-lantern.fzz]
2020-05-18 Laid out an improved small lantern board
    [small-lantern.fzz]
2020-05-18 Corrected resistor resistance
    [big-lantern.fzz, small-lantern.fzz]
2020-05-18 Corrected LED sizing
    [big-lantern.fzz, small-lantern.fzz]
2020-05-18 Created a tall variant for big lantern which is cleaner but less space efficient =/
    [big-lantern-tall.fzz]
2020-05-18 Moved reed switch to bottom of MCU for compactness
    [big-lantern.fzz]
2020-05-18 Moved reed switch back to size for ease of soldering and clarity, though 1 more wire to GND
    [big-lantern.fzz]
2020-05-18 Moved back reed switch again to centralize location, pushed down LEDs for clarity
    [big-lantern.fzz]
2020-05-18 Fixed wire color for reed switch on small lantern
    [small-lantern.fzz]
2020-05-19 Updated leads/wires coloring to indicate solder and running under board
    [big-lantern.fzz, small-lantern.fzz]
2020-05-19 Updated small lantern layout to avoid crossing at immovable pins
    [small-lantern.fzz]
2020-05-19 Updated small lantern to use long resistor lead for GND connection
    [small-lantern.fzz]
2020-05-20 Started adding magnet toggle updates to README but realizing we might have messed up with battery capacity -_-;;
2020-05-20 Finished README updates for magnet toggle
2020-05-20 Added attribution and cleaned up magnet-toggle folder
    [big-lantern-tall.fzz, schematic.fzz]
2020-05-20 Renamed attiny85 folder to magnet-toggle
    [big-lantern.fzz, small-lantern.fzz]
2020-05-20 Clarified considerations for toggle switch
2020-05-20 Added layout and board images
2020-05-21 Added BOM for magnet toggle variant
2020-05-21 Relocated images to before BOM
2020-05-21 Added battery to BOM
2020-10-14 Added Arduino header requirement for PlatformIO
2020-10-14 Tried messing with fuses and might have bricked an ATtiny ._.
2020-10-15 Playing with a known power configuration
2020-10-15 Adding TODOs to understand why what we expect to work, doesn't
    [main.cpp]
2020-10-15 Documented all our fuse options
2020-10-15 Started documenting lots of one-offs and whys. Discovered why we only got PCINT0_vect (needed to correct general interrupt register, GIMSK for INT0 -_-;;)
    [main.cpp]
2020-10-15 Cleaned up interrupt registers
2020-10-15 Attempting to catch falling edge only but it's not working as expected
    [main.cpp]
2020-10-15 Added note about interrupts being same behavior it seems
2020-10-25 Expanded all our power conservation descriptions
2020-10-25 Exploring actual power consumption in practice
2020-10-25 Confirmed that CKDIV8 does allow for lower current boot
2020-10-25 Added notes around not reprogramming remaining boards
